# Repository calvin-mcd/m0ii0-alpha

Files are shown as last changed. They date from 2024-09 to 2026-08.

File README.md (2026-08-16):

# m0ii0-alpha

alpha stagger pcb for the 40% kaWaii m0ii0 by [yohewi](https://github.com/yohewi).
 
## Layout

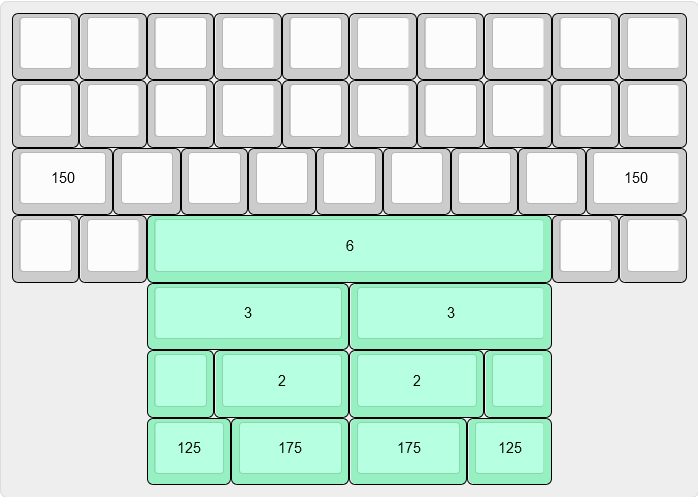
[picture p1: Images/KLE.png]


[Link](https://www.keyboard-layout-editor.com/#/gists/c427c1bf705222f226298ba031b6538b)

## Todo

- [x] order & test pcb

## Disclaimer

This PCB has been fully tested and confirmed to work. The members of the PCB development team are however not liable if you end up with a non-functional pcb. Order at your own risk. Support will not be provided but pull requests will be reviewed and possibly accepted.

## License

This project is released under the GPL v3 License. Please refer to the LICENCE file.

## Credits
	
As always big thanks to the many people who helped me and inspired this board!

Any questions, contact Calvin0563 on Discord.

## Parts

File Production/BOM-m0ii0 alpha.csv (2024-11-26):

Comment | Designator | Footprint | LCSC
boot | SW1 | SW_Push_SPST_NO_Alps_SKRK | C561519
1k | R8 | R_0402_1005Metric | C11702
100nF | C1,C10,C11,C12,C13,C14,C15,C5,C6,C9 | C_0402_1005Metric | C1525
10uF | C7 | C_0402_1005Metric | C15525
22pF | C2,C3 | C_0402_1005Metric | C1555
USB_C_Receptacle_USB2.0 | J1 | USB_C_Receptacle_HRO_TYPE-C-31-M-12 | C165948
RP2040 | U1 | RP2040-QFN-56 | C2040
27R | R1,R2 | R_0603_1608Metric | C25190
1k | R4 | R_0402_1005Metric | C25543
5k1 | R5,R6,R7 | R_0402_1005Metric | C25905
USBLC6-2SC6 | U2 | SOT-23-6 | C2827654
W25Q16JVUXIQ | IC1 | SON50P300X200X60-9N | C2843335
1uF | C16,C17,C4,C8 | C_0402_1005Metric | C52923
XC6206PxxxMR-Regulator_Linear | U3 | SOT-23 | C5446
Reset | SWR1 | SW_Push_SPST_NO_Alps_SKRK | C561519
500mA | F1 | Fuse_1206_3216Metric | C70076
D_Small | D1,D10,D11,D12,D13,D14,D15,D16,D17,D18,D19,D2,D20,D21,D22,D23,D24,D25,D26,D27,D28,D29,D3,D30,D31,D32,D33,D34,D35,D36,D37,D38,D4,D5,D6,D7,D8,D9 | D_SOD-123F | C81598
12MHz | Y1 | Crystal_SMD_3225-4Pin_3.2x2.5mm | C9002

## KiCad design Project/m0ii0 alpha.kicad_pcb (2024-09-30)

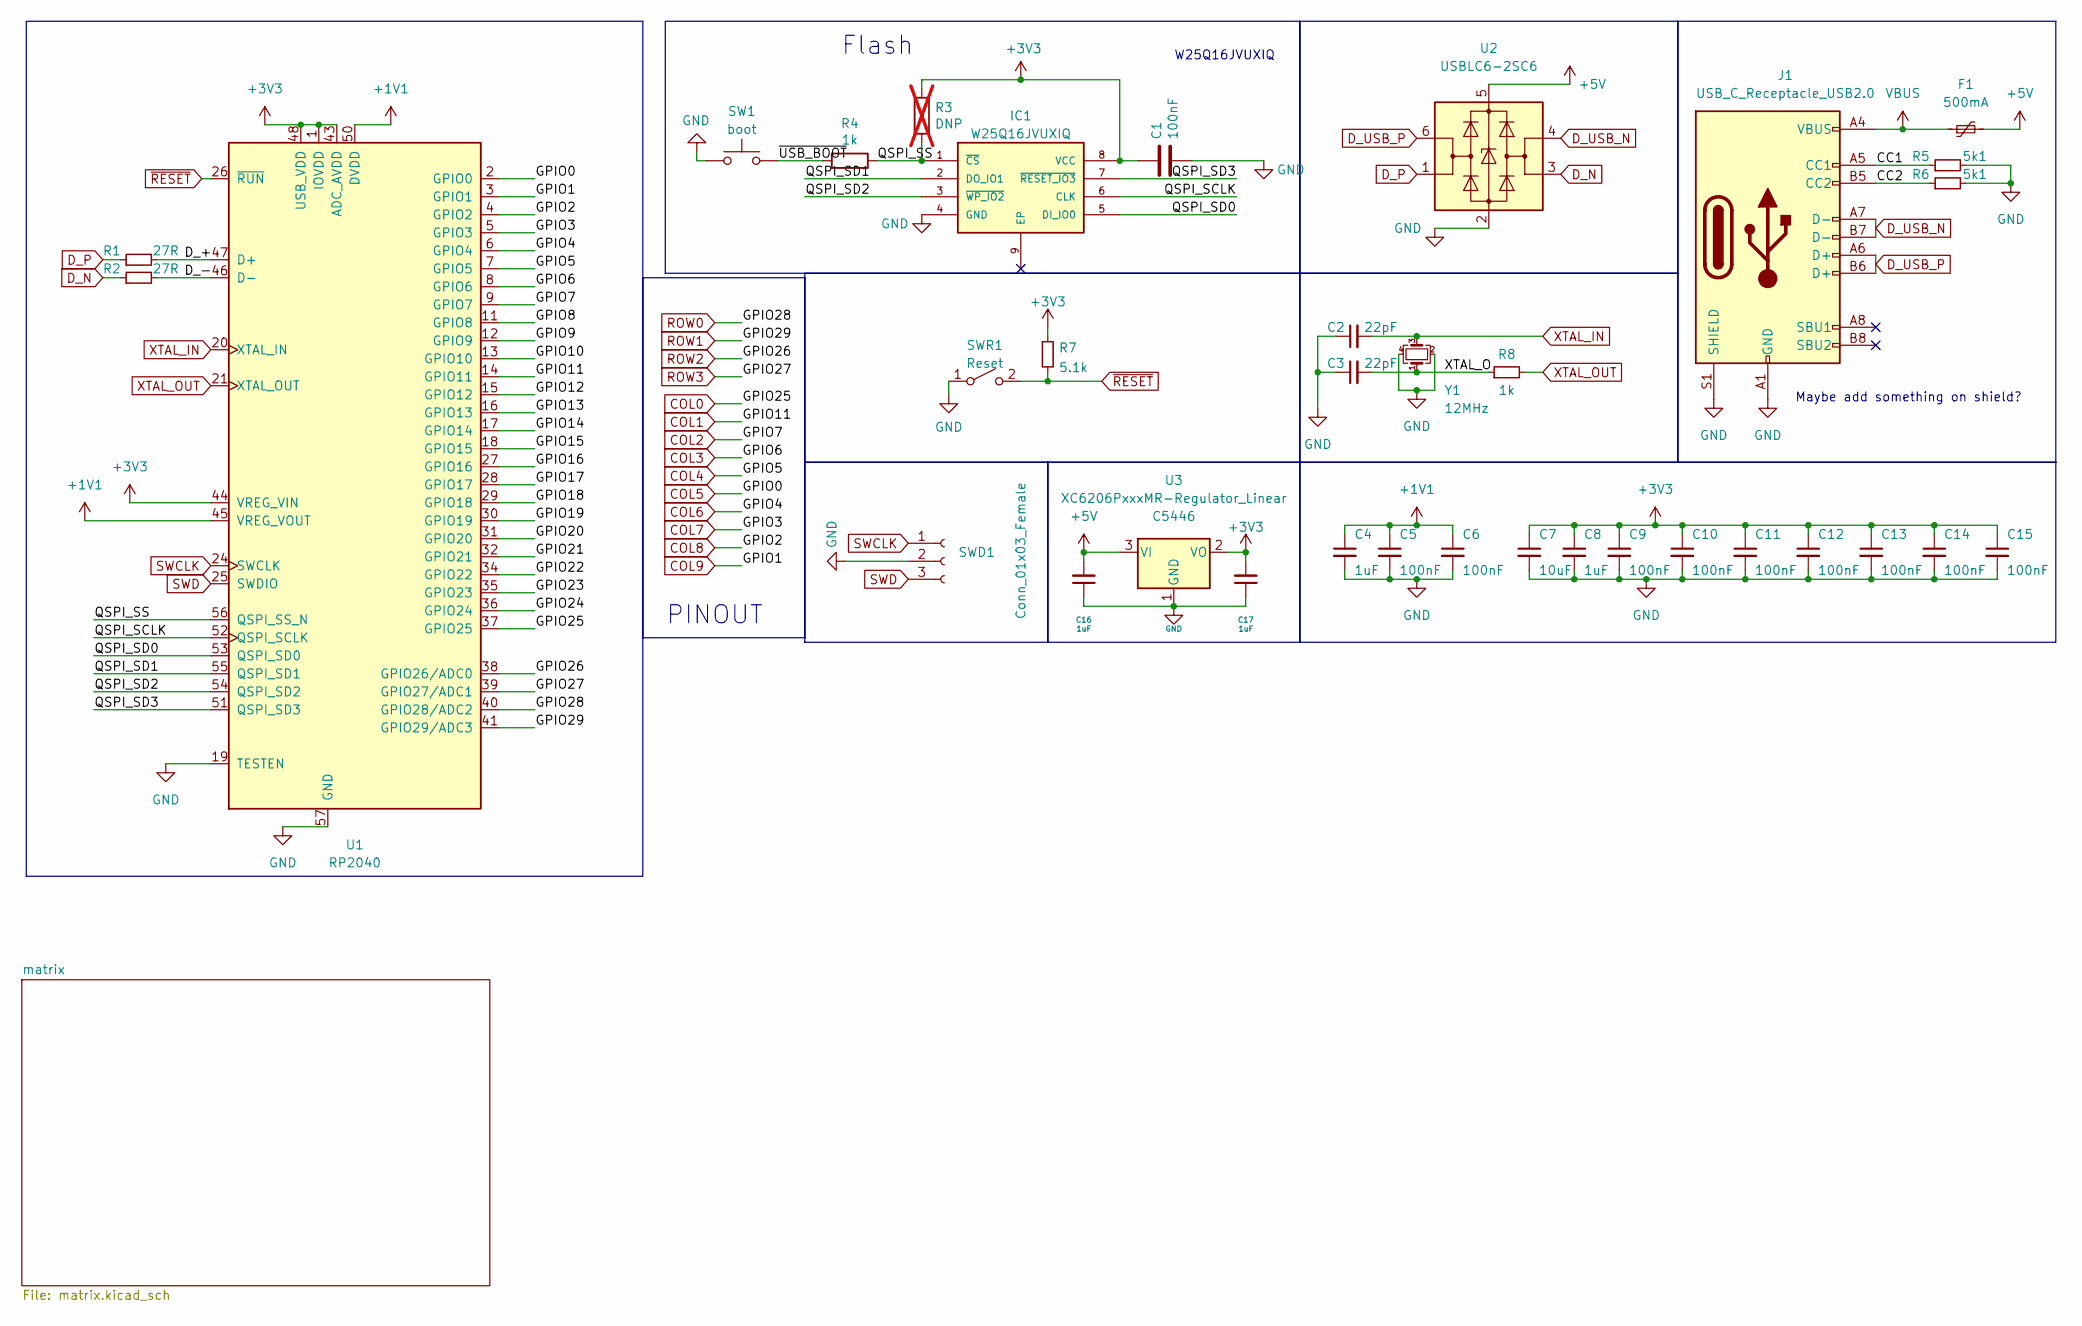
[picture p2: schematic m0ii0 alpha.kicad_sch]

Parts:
C1, C5, C6, C9, C10, C11, C12, C13, C14, C15: 100nF; C_0402_1005Metric; LCSC C1525
C2, C3: 22pF; C_0402_1005Metric; LCSC C1555
C4, C8, C16, C17: 1uF; C_0402_1005Metric; LCSC C52923
C7: 10uF; C_0402_1005Metric; LCSC C15525
F1: 500mA; Fuse_1206_3216Metric; LCSC C70076
IC1: W25Q16JVUXIQ; SON50P300X200X60-9N; MANUFACTURER_PART_NUMBER W25Q16JVUXIQ; LCSC Part C2843335
J1: USB_C_Receptacle_USB2.0; USB_C_Receptacle_HRO_TYPE-C-31-M-12; LCSC C165948
R1, R2: 27R; R_0603_1608Metric; LCSC C25190
R3: DNP; C_0402_1005Metric; LCSC C25905; not fitted
R4: 1k; R_0402_1005Metric; LCSC Part C25543
R5, R6: 5k1; R_0402_1005Metric; LCSC C25905
R7: 5.1k; R_0402_1005Metric
R8: 1k; R_0402_1005Metric; LCSC C11702
SW1: boot; SW_Push_SPST_NO_Alps_SKRK; LCSC Part C115351
SWD1: Conn_01x03_Female; PinHeader_1x03_P2.54mm_Vertical
SWR1: Reset; SW_Push_SPST_NO_Alps_SKRK
U1: RP2040; RP2040-QFN-56; LCSC C2040
U2: USBLC6-2SC6; SOT-23-6; LCSC C2827654
U3: XC6206PxxxMR-Regulator_Linear; SOT-23; LCSC C5446
Y1: 12MHz; Crystal_SMD_3225-4Pin_3.2x2.5mm; LCSC C9002

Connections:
+1V1: C4.1, C5.1, C6.1, U1.23 (DVDD), U1.45 (VREG_VOUT), U1.50 (DVDD)
+3V3: C1.1, C7.1, C8.1, C9.1, C10.1, C11.1, C12.1, C13.1, C14.1, C15.1, C17.2, IC1.8 (VCC), R3.1, R7.1, U1.1 (IOVDD), U1.10 (IOVDD), U1.22 (IOVDD), U1.33 (IOVDD), U1.42 (IOVDD), U1.43 (ADC_AVDD), U1.44 (VREG_VIN), U1.48 (USB_VDD), U1.49 (IOVDD), U3.2 (VO)
+5V: C16.2, F1.2, U2.5 (VBUS), U3.3 (VI)
/CC1: J1.A5 (CC1), R5.1
/CC2: J1.B5 (CC2), R6.1
/D_+: R1.2, U1.47 (D+)
/D_-: R2.2, U1.46 (D-)
/GPIO8: U1.11 (GPIO8)
/GPIO9: U1.12 (GPIO9)
/GPIO10: U1.13 (GPIO10)
/GPIO12: U1.15 (GPIO12)
/GPIO13: U1.16 (GPIO13)
/GPIO14: U1.17 (GPIO14)
/GPIO15: U1.18 (GPIO15)
/GPIO16: U1.27 (GPIO16)
/GPIO17: U1.28 (GPIO17)
/GPIO18: U1.29 (GPIO18)
/GPIO19: U1.30 (GPIO19)
/GPIO20: U1.31 (GPIO20)
/GPIO21: U1.32 (GPIO21)
/GPIO22: U1.34 (GPIO22)
/GPIO23: U1.35 (GPIO23)
/GPIO24: U1.36 (GPIO24)
/QSPI_SCLK: IC1.6 (CLK), U1.52 (QSPI_SCLK)
/QSPI_SD0: IC1.5 (DI_IO0), U1.53 (QSPI_SD0)
/QSPI_SD1: IC1.2 (DO_IO1), U1.55 (QSPI_SD1)
/QSPI_SD2: IC1.3 (~WP_IO2), U1.54 (QSPI_SD2)
/QSPI_SD3: IC1.7 (~RESET_IO3), U1.51 (QSPI_SD3)
/QSPI_SS: IC1.1 (~CS), R3.2, R4.1, U1.56 (QSPI_SS_N)
/XTAL_O: C3.2, R8.1, Y1.1
/~USB_BOOT: R4.2, SW1.2
COL0: U1.37 (GPIO25); also elsewhere on the board
COL1: U1.14 (GPIO11); also elsewhere on the board
COL2: U1.9 (GPIO7); also elsewhere on the board
COL3: U1.8 (GPIO6); also elsewhere on the board
COL4: U1.7 (GPIO5); also elsewhere on the board
COL5: U1.2 (GPIO0); also elsewhere on the board
COL6: U1.6 (GPIO4); also elsewhere on the board
COL7: U1.5 (GPIO3); also elsewhere on the board
COL8: U1.4 (GPIO2); also elsewhere on the board
COL9: U1.3 (GPIO1); also elsewhere on the board
D_N: R2.1, U2.3 (I/O2)
D_P: R1.1, U2.1 (I/O1)
D_USB_N: J1.A7 (D-), J1.B7 (D-), U2.4 (I/O2)
D_USB_P: J1.A6 (D+), J1.B6 (D+), U2.6 (I/O1)
GND: C1.2, C2.1, C3.1, C4.2, C5.2, C6.2, C7.2, C8.2, C9.2, C10.2, C11.2, C12.2, C13.2, C14.2, C15.2, C16.1, C17.1, IC1.4 (GND), J1.A1 (GND), J1.A12 (GND), J1.B1 (GND), J1.B12 (GND), J1.S1 (SHIELD), R5.2, R6.2, SW1.1, SWD1.2, SWR1.1 (A), U1.19 (TESTEN), U1.57 (GND), U2.2 (GND), U3.1 (GND), Y1.2, Y1.4
ROW0: U1.40 (GPIO28/ADC2); also elsewhere on the board
ROW1: U1.41 (GPIO29/ADC3); also elsewhere on the board
ROW2: U1.38 (GPIO26/ADC0); also elsewhere on the board
ROW3: U1.39 (GPIO27/ADC1); also elsewhere on the board
SWCLK: SWD1.1, U1.24 (SWCLK)
SWD: SWD1.3, U1.25 (SWDIO)
VBUS: F1.1, J1.A4 (VBUS), J1.A9 (VBUS), J1.B4 (VBUS), J1.B9 (VBUS)
XTAL_IN: C2.2, U1.20 (XTAL_IN), Y1.3
XTAL_OUT: R8.2, U1.21 (XTAL_OUT)
~RESET: R7.2, SWR1.2 (B), U1.26 (~RUN)

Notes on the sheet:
Flash
Maybe add something on shield?
PINOUT
W25Q16JVUXIQ

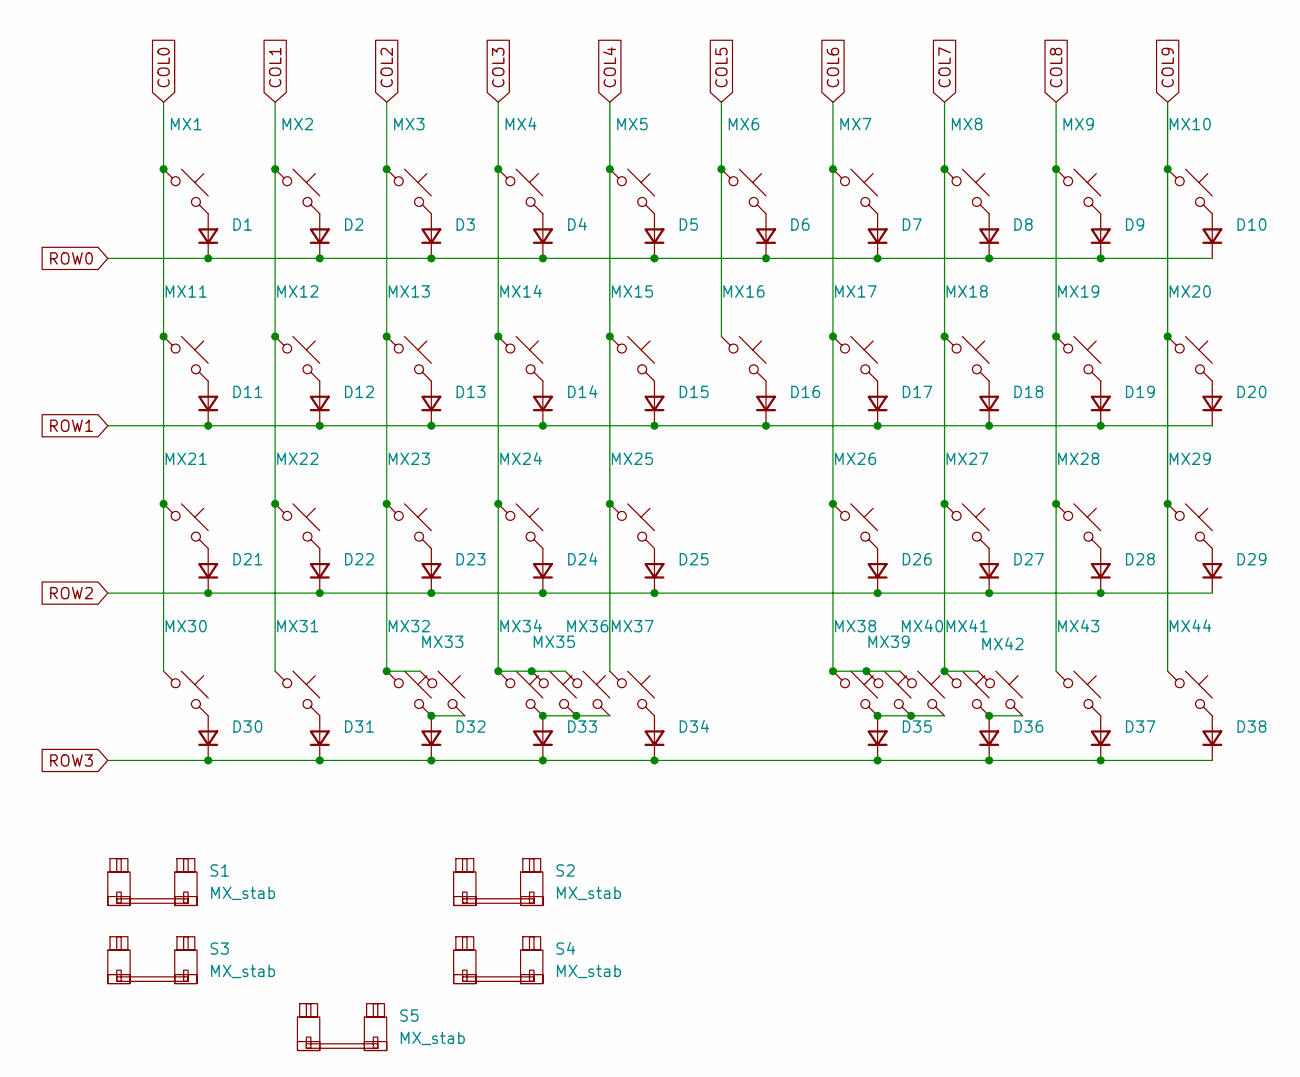
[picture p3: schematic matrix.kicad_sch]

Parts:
D1, D2, D3, D4, D5, D6, D7, D8, D9, D10, D11, D12, D13, D14, D15, D16, D17, D18, D19, D20, D21, D22, D23, D24, D25, D26, D27, D28, D29, D30, D31, D32, D33, D34, D35, D36, D37, D38: D_Small; D_SOD-123F
MX1, MX2, MX3, MX4, MX5, MX6, MX7, MX8, MX9, MX10, MX11, MX12, MX13, MX14, MX15, MX16, MX17, MX18, MX19, MX20, MX22, MX23, MX24, MX25, MX26, MX27, MX28, MX30, MX31, MX32, MX34, MX35, MX37, MX38, MX39, MX41, MX43, MX44: MX_SW_solder; SW_MX_1u
MX21, MX29: MX_SW_solder; SW_MX_1.5u
MX33, MX42: MX_SW_solder; SW_MX_1.25u
MX36, MX40: MX_SW_solder; SW_MX_1.75u
S1, S2: MX_stab; STAB_MX_P_2u
S3, S4: MX_stab; STAB_MX_P_3u
S5: MX_stab; STAB_MX_P_6u

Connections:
COL0: MX1.1, MX11.1, MX21.1, MX30.1; also elsewhere on the board
COL1: MX2.1, MX12.1, MX22.1, MX31.1; also elsewhere on the board
COL2: MX3.1, MX13.1, MX23.1, MX32.1, MX33.1; also elsewhere on the board
COL3: MX4.1, MX14.1, MX24.1, MX34.1, MX35.1, MX36.1; also elsewhere on the board
COL4: MX5.1, MX15.1, MX25.1, MX37.1; also elsewhere on the board
COL5: MX6.1, MX16.1; also elsewhere on the board
COL6: MX7.1, MX17.1, MX26.1, MX38.1, MX39.1, MX40.1; also elsewhere on the board
COL7: MX8.1, MX18.1, MX27.1, MX41.1, MX42.1; also elsewhere on the board
COL8: MX9.1, MX19.1, MX28.1, MX43.1; also elsewhere on the board
COL9: MX10.1, MX20.1, MX29.1, MX44.1; also elsewhere on the board
unnamed: D1.2 (A), MX1.2
unnamed: D2.2 (A), MX2.2
unnamed: D3.2 (A), MX3.2
unnamed: D4.2 (A), MX4.2
unnamed: D5.2 (A), MX5.2
unnamed: D6.2 (A), MX6.2
unnamed: D7.2 (A), MX7.2
unnamed: D8.2 (A), MX8.2
unnamed: D9.2 (A), MX9.2
unnamed: D10.2 (A), MX10.2
unnamed: D11.2 (A), MX11.2
unnamed: D12.2 (A), MX12.2
unnamed: D13.2 (A), MX13.2
unnamed: D14.2 (A), MX14.2
unnamed: D15.2 (A), MX15.2
unnamed: D16.2 (A), MX16.2
unnamed: D17.2 (A), MX17.2
unnamed: D18.2 (A), MX18.2
unnamed: D19.2 (A), MX19.2
unnamed: D20.2 (A), MX20.2
unnamed: D21.2 (A), MX21.2
unnamed: D22.2 (A), MX22.2
unnamed: D23.2 (A), MX23.2
unnamed: D24.2 (A), MX24.2
unnamed: D25.2 (A), MX25.2
unnamed: D26.2 (A), MX26.2
unnamed: D27.2 (A), MX27.2
unnamed: D28.2 (A), MX28.2
unnamed: D29.2 (A), MX29.2
unnamed: D30.2 (A), MX30.2
unnamed: D31.2 (A), MX31.2
unnamed: D32.2 (A), MX32.2, MX33.2
unnamed: D33.2 (A), MX34.2, MX35.2, MX36.2
unnamed: D34.2 (A), MX37.2
unnamed: D35.2 (A), MX38.2, MX39.2, MX40.2
unnamed: D36.2 (A), MX41.2, MX42.2
unnamed: D37.2 (A), MX43.2
unnamed: D38.2 (A), MX44.2
ROW0: D1.1 (K), D2.1 (K), D3.1 (K), D4.1 (K), D5.1 (K), D6.1 (K), D7.1 (K), D8.1 (K), D9.1 (K), D10.1 (K); also elsewhere on the board
ROW1: D11.1 (K), D12.1 (K), D13.1 (K), D14.1 (K), D15.1 (K), D16.1 (K), D17.1 (K), D18.1 (K), D19.1 (K), D20.1 (K); also elsewhere on the board
ROW2: D21.1 (K), D22.1 (K), D23.1 (K), D24.1 (K), D25.1 (K), D26.1 (K), D27.1 (K), D28.1 (K), D29.1 (K); also elsewhere on the board
ROW3: D30.1 (K), D31.1 (K), D32.1 (K), D33.1 (K), D34.1 (K), D35.1 (K), D36.1 (K), D37.1 (K), D38.1 (K); also elsewhere on the board

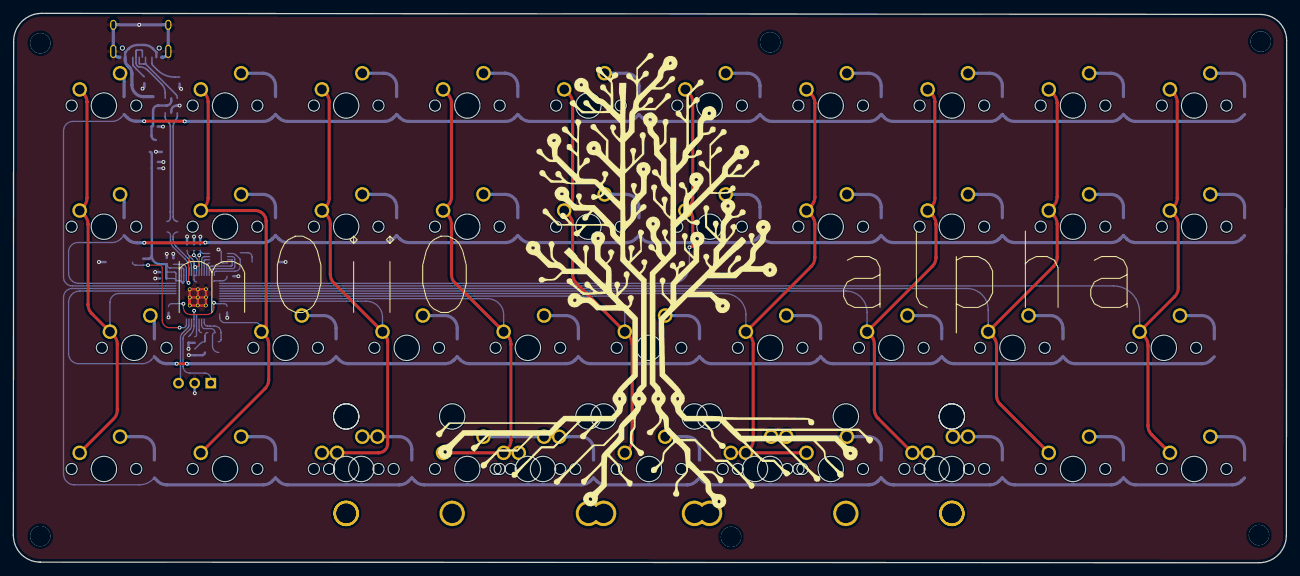
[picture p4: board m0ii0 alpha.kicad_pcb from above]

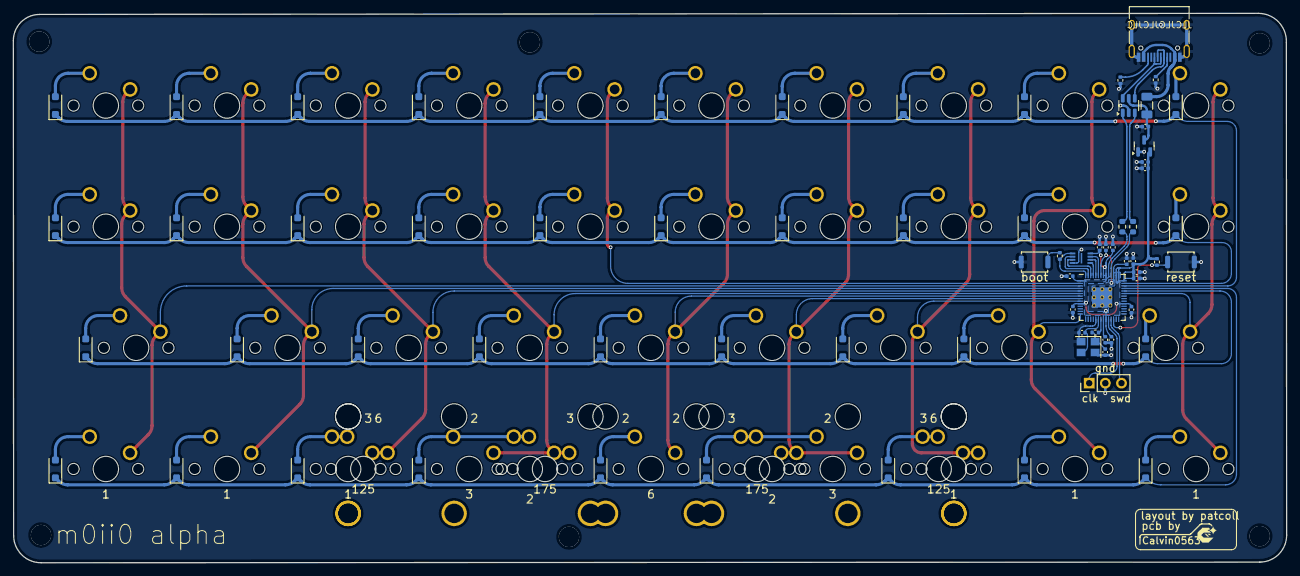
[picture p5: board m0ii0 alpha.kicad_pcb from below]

Board: 2 copper layers, 200.2 x 86.4 mm, 121 parts (72 on the bottom side), 78 nets.

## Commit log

2024-09-22 added silkscreen
    [m0ii0 alpha-B_Cu.gbr, m0ii0 alpha-B_Mask.gbr, m0ii0 alpha-B_Paste.gbr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]
2024-09-30 firmware & readmen
    [175u plate-B_Cu.gbr, 175u plate-B_Mask.gbr, 175u plate-B_Paste.gbr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]
2025-03-23 Update m0ii0 alpha.kicad_prl
